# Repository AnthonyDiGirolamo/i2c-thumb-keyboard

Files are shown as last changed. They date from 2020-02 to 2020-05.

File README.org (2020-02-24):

* i2c-thumb-keyboard

  Handheld tactile switch keyboard using the [[http://www.ti.com/product/TCA8418][TCA8418]].

  For more info see these [[https://hackaday.io/project/162281-teensy-thumb-keyboard][hackaday.io]] posts:
  - [[https://hackaday.io/project/162281-teensy-thumb-keyboard/log/164899-working-on-v2][Working on v2]]
  - [[https://hackaday.io/project/162281-teensy-thumb-keyboard/log/165015-raspberry-pi-i2c-connection][Raspberry Pi i2c Connection]]

** v1.0 Photo
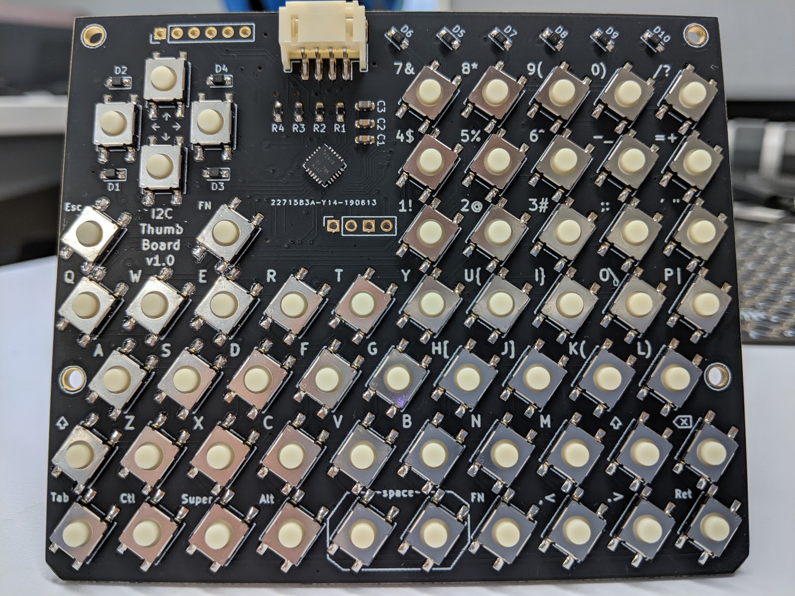
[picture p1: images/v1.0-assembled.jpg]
   

** BOM
   - 60x [[https://www.digikey.com/product-detail/en/panasonic-electronic-components/EVQ-Q2B03W/P12932SCT-ND/762922][EVQ-Q2B03W Tactile Switch]] (SW1-SW60)
   - 10x [[https://lcsc.com/product-detail/Switching-Diode_1N4148WS_C110221.html][1N4148WS Diode]] (D1-D10)
   - 1x [[https://lcsc.com/product-detail/Interface-ICs_TI_TCA8418RTWR_TCA8418RTWR_C138713.html][TCA8418]]
   - 2x [[https://lcsc.com/product-detail/Chip-Resistor-Surface-Mount_Uniroyal-Elec-0603WAF1002T5E_C25804.html][0603 10k Resistor]] (R1, R4)
   - 2x [[https://lcsc.com/product-detail/Chip-Resistor-Surface-Mount_Uniroyal-Elec-0603WAF4701T5E_C23162.html][0603 4.7k Resistor]] (R2, R3)
   - 2x [[https://lcsc.com/product-detail/Multilayer-Ceramic-Capacitors-MLCC-SMD-SMT_SAMSUNG_CL10B104KA8NNNC_100nF-104-10-25V_C1590.html][0603 0.1uF Capacitor]] (C1, C2)
   - 1x [[https://lcsc.com/product-detail/Multilayer-Ceramic-Capacitors-MLCC-SMD-SMT_SAMSUNG_CL10A106MQ8NNNC_10uF-106-20-6-3V_C1691.html][0603 10uF Capacitor]] (C3)
   - Optional:
     - 1x [[https://www.digikey.com/product-detail/en/jst-sales-america-inc/S4B-PH-SM4-TB(LF)(SN)/455-1751-1-ND/926848][JST PH Connector Socket S4B-PH-SM4-TB(LF)(SN)]]
     - 1x [[https://www.digikey.com/product-detail/en/jst-sales-america-inc/A04KR04KR26E152B/455-3151-ND/6194806][JST KR Jumper Cable]]

** Prior Work

   [[https://github.com/AnthonyDiGirolamo/teensy-thumb-keyboard][teensy-thumb-keyboard]]

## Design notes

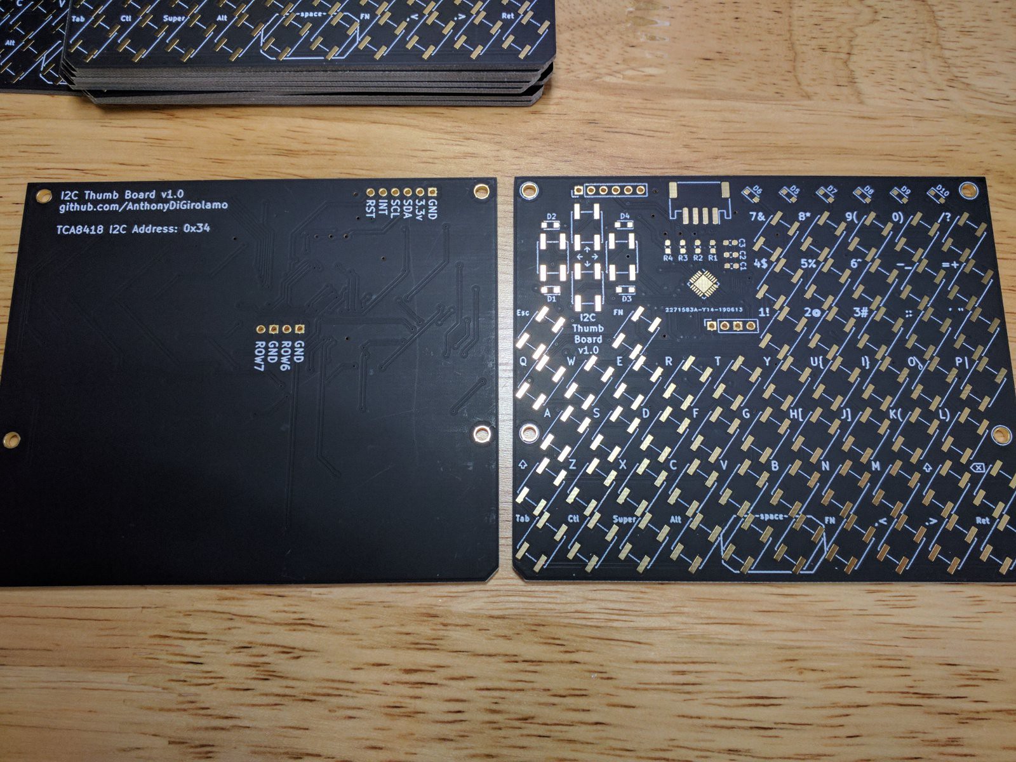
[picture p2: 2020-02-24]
images/v1.0-front-back.jpg

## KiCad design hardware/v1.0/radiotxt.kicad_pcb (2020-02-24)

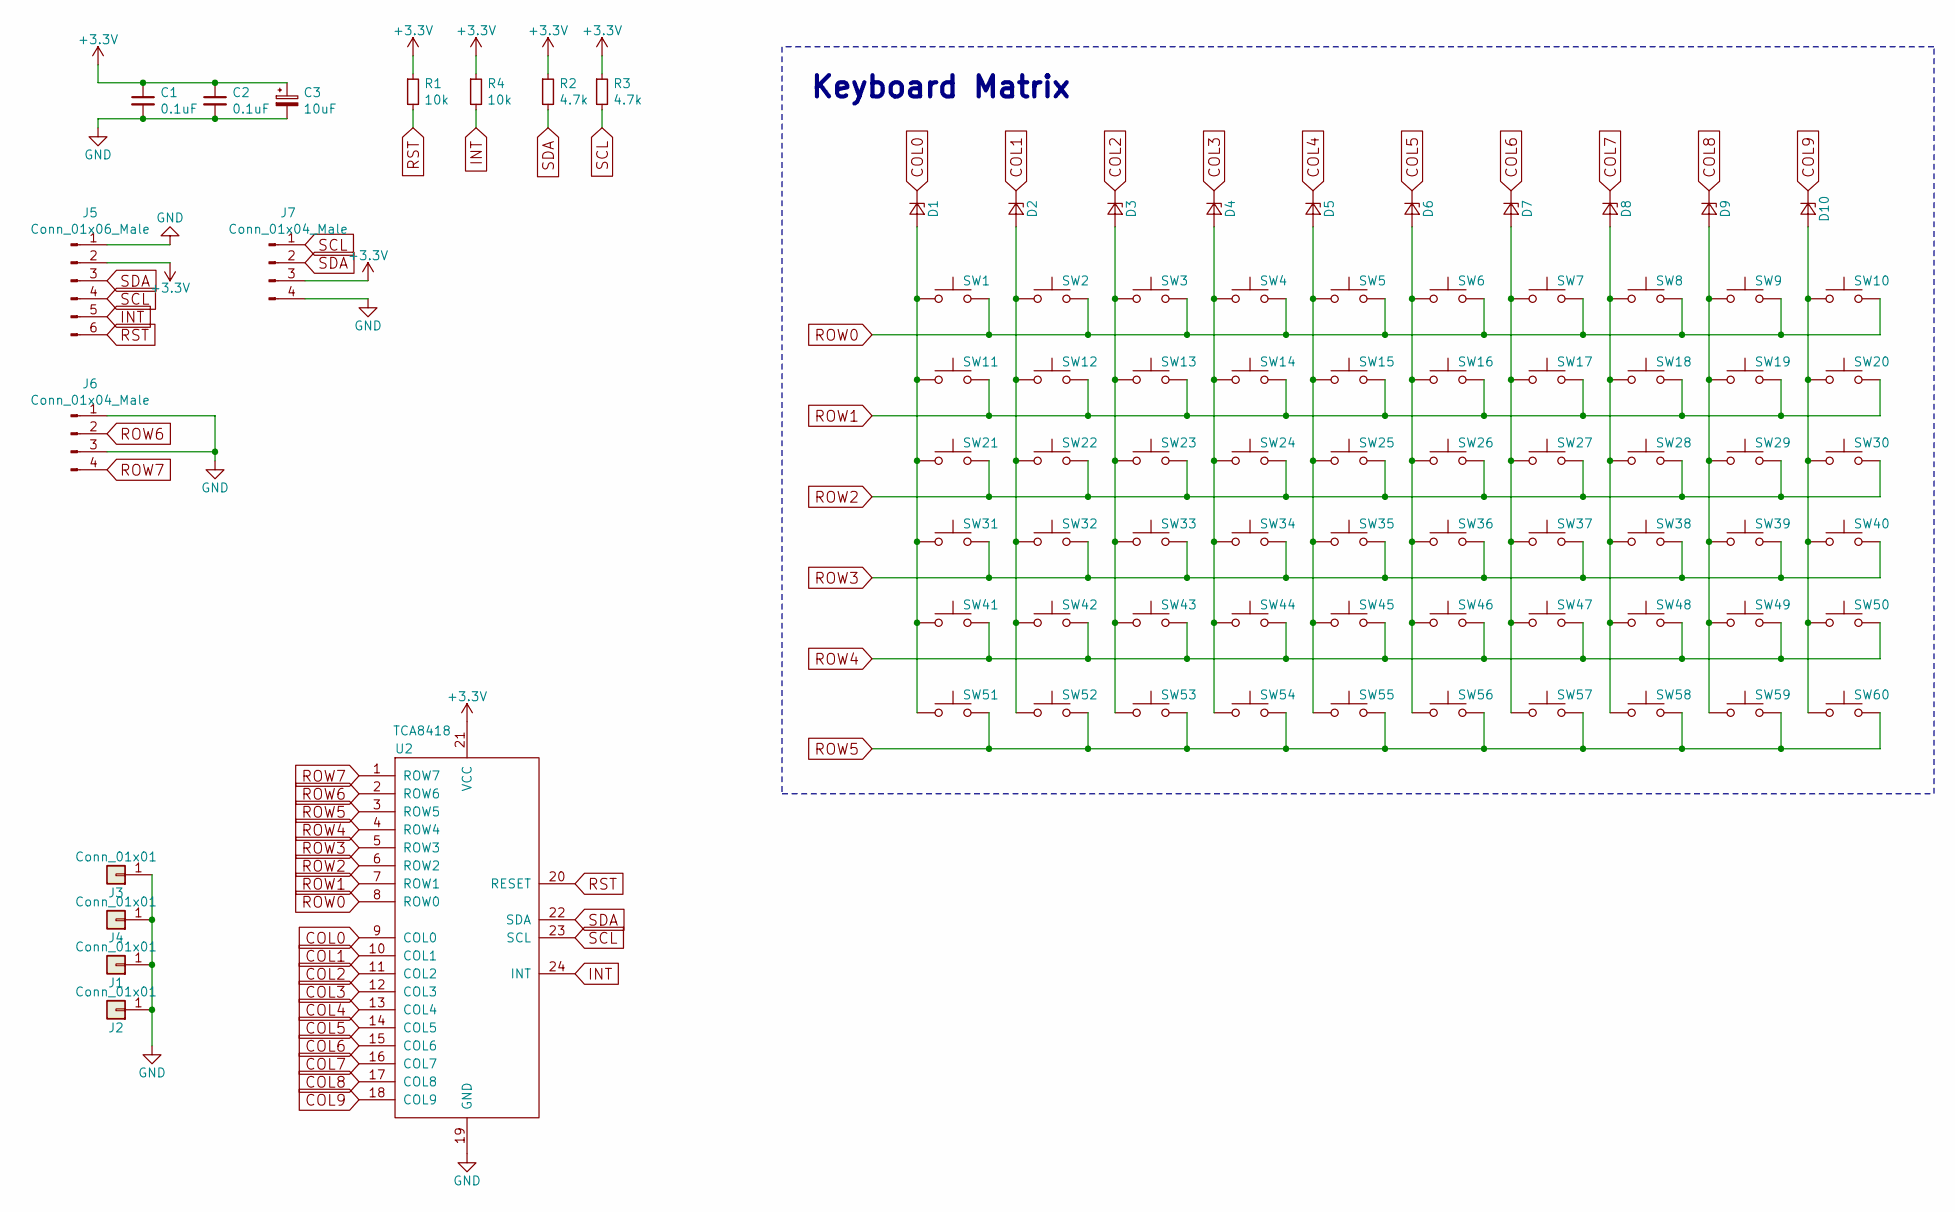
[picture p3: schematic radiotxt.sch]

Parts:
C1, C2: 0.1uF; C_0603_1608Metric_Pad1.05x0.95mm_HandSolder
C3: 10uF; C_0603_1608Metric_Pad1.05x0.95mm_HandSolder
D1, D2, D3, D4, D5, D6, D7, D8, D9, D10: D_Zener_Small; D_SOD-323_HandSoldering
J1, J2, J3, J4: Conn_01x01; 2.5MountingHole
J5: Conn_01x06_Male; PinHeader_1x06_P2.54mm_Vertical
J6: Conn_01x04_Male; PinSocket_1x04_P2.54mm_Vertical
J7: Conn_01x04_Male; JST_PH_S4B-PH-SM4-TB_1x04-1MP_P2.00mm_Horizontal
R1, R4: 10k; R_0603_1608Metric_Pad1.05x0.95mm_HandSolder
R2, R3: 4.7k; R_0603_1608Metric_Pad1.05x0.95mm_HandSolder
SW1, SW2, SW3, SW4, SW5, SW6, SW7, SW8, SW9, SW10, SW11, SW12, SW13, SW14, SW15, SW16, SW17, SW18, SW19, SW20, SW21, SW22, SW23, SW24, SW25, SW26, SW27, SW28, SW29, SW30, SW31, SW32, SW33, SW34, SW35, SW36, SW37, SW38, SW39, SW40, SW41, SW42, SW43, SW44, SW45, SW46, SW47, SW48, SW49, SW50, SW51, SW52, SW53, SW54, SW55, SW56, SW57, SW58, SW59, SW60: SW_Push; SW_SPST_EVQQ2
U2: TCA8418; WQFN-24-1EP_4x4mm_P0.5mm_EP2.7x2.7mm

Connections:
+3V3: C1.1, C2.1, C3.1, J5.2, J7.3, R1.1, R2.1, R3.1, R4.1, U2.21 (VCC)
COL0: D1.1 (K), U2.9 (COL0)
COL1: D2.1 (K), U2.10 (COL1)
COL2: D3.1 (K), U2.11 (COL2)
COL3: D4.1 (K), U2.12 (COL3)
COL4: D5.1 (K), U2.13 (COL4)
COL5: D6.1 (K), U2.14 (COL5)
COL6: D7.1 (K), U2.15 (COL6)
COL7: D8.1 (K), U2.16 (COL7)
COL8: D9.1 (K), U2.17 (COL8)
COL9: D10.1 (K), U2.18 (COL9)
GND: C1.2, C2.2, C3.2, J1.1, J2.1, J3.1, J4.1, J5.1, J6.1, J6.3, J7.4, U2.19 (GND)
INT: J5.5, R4.2, U2.24 (INT)
unnamed: D1.2 (A), SW1.1, SW11.1, SW21.1, SW31.1, SW41.1, SW51.1
unnamed: D2.2 (A), SW2.1, SW12.1, SW22.1, SW32.1, SW42.1, SW52.1
unnamed: D3.2 (A), SW3.1, SW13.1, SW23.1, SW33.1, SW43.1, SW53.1
unnamed: D4.2 (A), SW4.1, SW14.1, SW24.1, SW34.1, SW44.1, SW54.1
unnamed: D5.2 (A), SW5.1, SW15.1, SW25.1, SW35.1, SW45.1, SW55.1
unnamed: D6.2 (A), SW6.1, SW16.1, SW26.1, SW36.1, SW46.1, SW56.1
unnamed: D7.2 (A), SW7.1, SW17.1, SW27.1, SW37.1, SW47.1, SW57.1
unnamed: D8.2 (A), SW8.1, SW18.1, SW28.1, SW38.1, SW48.1, SW58.1
unnamed: D9.2 (A), SW9.1, SW19.1, SW29.1, SW39.1, SW49.1, SW59.1
unnamed: D10.2 (A), SW10.1, SW20.1, SW30.1, SW40.1, SW50.1, SW60.1
ROW0: SW1.2, SW2.2, SW3.2, SW4.2, SW5.2, SW6.2, SW7.2, SW8.2, SW9.2, SW10.2, U2.8 (ROW0)
ROW1: SW11.2, SW12.2, SW13.2, SW14.2, SW15.2, SW16.2, SW17.2, SW18.2, SW19.2, SW20.2, U2.7 (ROW1)
ROW2: SW21.2, SW22.2, SW23.2, SW24.2, SW25.2, SW26.2, SW27.2, SW28.2, SW29.2, SW30.2, U2.6 (ROW2)
ROW3: SW31.2, SW32.2, SW33.2, SW34.2, SW35.2, SW36.2, SW37.2, SW38.2, SW39.2, SW40.2, U2.5 (ROW3)
ROW4: SW41.2, SW42.2, SW43.2, SW44.2, SW45.2, SW46.2, SW47.2, SW48.2, SW49.2, SW50.2, U2.4 (ROW4)
ROW5: SW51.2, SW52.2, SW53.2, SW54.2, SW55.2, SW56.2, SW57.2, SW58.2, SW59.2, SW60.2, U2.3 (ROW5)
ROW6: J6.2, U2.2 (ROW6)
ROW7: J6.4, U2.1 (ROW7)
RST: J5.6, R1.2, U2.20 (RESET)
SCL: J5.4, J7.1, R3.2, U2.23 (SCL)
SDA: J5.3, J7.2, R2.2, U2.22 (SDA)

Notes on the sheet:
Keyboard Matrix

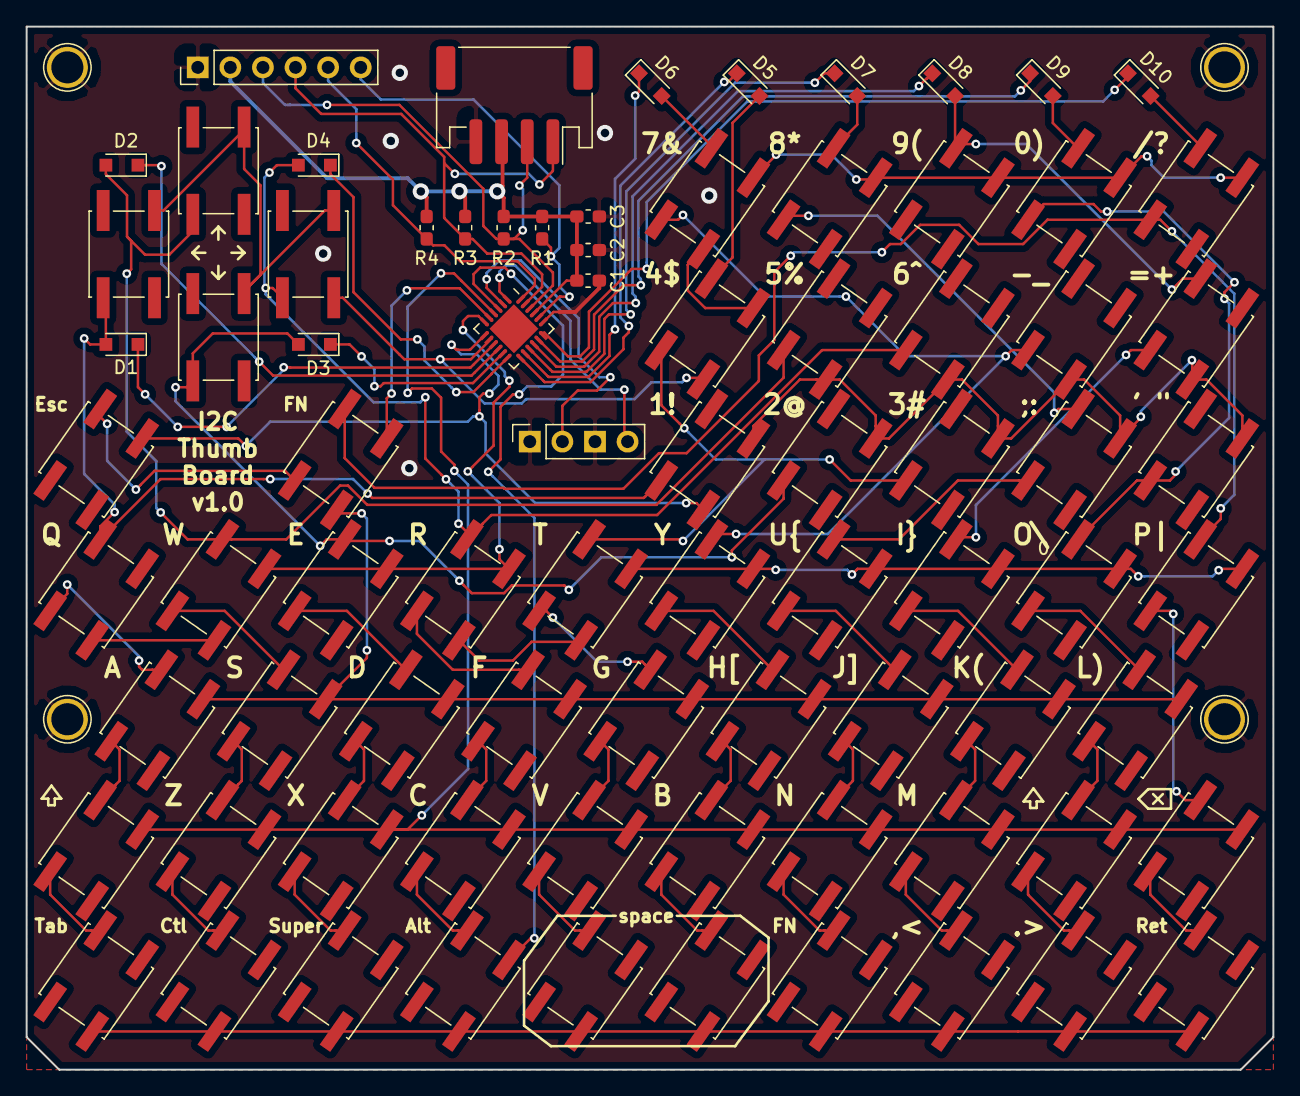
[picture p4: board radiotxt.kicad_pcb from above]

Board: 2 copper layers, 97.2 x 81.3 mm, 85 parts (0 on the bottom side), 34 nets.

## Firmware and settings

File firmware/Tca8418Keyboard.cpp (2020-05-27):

#include "Tca8418Keyboard.h"

Tca8418Keyboard::Tca8418Keyboard(uint8_t numrows, uint8_t numcols) {
  tca8418_address = TCA8418_I2C_ADDRESS;
  num_rows = numrows;
  num_cols = numcols;

  delta_micros = 0;
  last_update_micros = 0;
  this_update_micros = 0;

  pressed_list = new PressedKey[KEY_EVENT_LIST_SIZE];
  released_list = new ReleasedKey[KEY_EVENT_LIST_SIZE];
  matrix_state = new uint16_t[num_rows];
  matrix_state_prev = new uint16_t[num_rows];

}

Tca8418Keyboard::~Tca8418Keyboard(void) {
  delete [] matrix_state_prev;
  delete [] matrix_state;
  delete [] pressed_list;
  delete [] released_list;
}

void Tca8418Keyboard::begin(void) {
  Wire.begin();

  /*
    | ADDRESS | REGISTER NAME | REGISTER DESCRIPTION | BIT7 | BIT6 | BIT5 | BIT4 | BIT3 | BIT2 | BIT1 | BIT0 |
    |---------+---------------+----------------------+------+------+------+------+------+------+------+------|
    |    0x1D | KP_GPIO1      | Keypad/GPIO Select 1 | ROW7 | ROW6 | ROW5 | ROW4 | ROW3 | ROW2 | ROW1 | ROW0 |
    |    0x1E | KP_GPIO2      | Keypad/GPIO Select 2 | COL7 | COL6 | COL5 | COL4 | COL3 | COL2 | COL1 | COL0 |
    |    0x1F | KP_GPIO3      | Keypad/GPIO Select 3 | N/A  | N/A  | N/A  | N/A  | N/A  | N/A  | COL9 | COL8 |
  */

  // everything enabled in key scan mode
  uint8_t enabled_rows = 0x3F;
  uint16_t enabled_cols = 0x3FF;

  write(REGISTER_KP_GPIO1, enabled_rows);
  write(REGISTER_KP_GPIO2, (uint8_t)(0xFF & enabled_cols));
  write(REGISTER_KP_GPIO3, (uint8_t)(0x03 & (enabled_cols >> 8)));

  /*
    BIT: NAME

    7: AI
    Auto-increment for read and write operations; See below table for more information
    0 = disabled
    1 = enabled

    6: GPI_E_CFG
    GPI event mode configuration
    0 = GPI events are tracked when keypad is locked
    1 = GPI events are not tracked when keypad is locked

    5: OVR_FLOW_M
    Overflow mode
    0 = disabled; Overflow data is lost
    1 = enabled; Overflow data shifts with last event pushing first event out

    4: INT_CFG
    Interrupt configuration
    0 = processor interrupt remains asserted (or low) if host tries to clear interrupt while there is
    still a pending key press, key release or GPI interrupt
    1 = processor interrupt is deasserted for 50 μs and reassert with pending interrupts

    3: OVR_FLOW_IEN
    Overflow interrupt enable
    0 = disabled; INT is not asserted if the FIFO overflows
    1 = enabled; INT becomes asserted if the FIFO overflows

    2: K_LCK_IEN
    Keypad lock interrupt enable
    0 = disabled; INT is not asserted after a correct unlock key sequence
    1 = enabled; INT becomes asserted after a correct unlock key sequence

    1: GPI_IEN
    GPI interrupt enable to host processor
    0 = disabled; INT is not asserted for a change on a GPI
    1 = enabled; INT becomes asserted for a change on a GPI

    0: KE_IEN
    Key events interrupt enable to host processor
    0 = disabled; INT is not asserted when a key event occurs
    1 = enabled; INT becomes asserted when a key event occurs
   */

  // 10111001 xB9 -- fifo overflow enabled
  // 10011001 x99 -- fifo overflow disabled
  write(REGISTER_CFG, 0x99);

  clear_released_list();
  clear_pressed_list();

  delayMicroseconds(100);
}

void Tca8418Keyboard::write(uint8_t register_address, uint8_t data) {
  Wire.beginTransmission(tca8418_address);
  Wire.write((uint8_t) register_address);
  Wire.write((uint8_t) data);
  Wire.endTransmission();
}

bool Tca8418Keyboard::read(uint8_t register_address, uint8_t *data) {
  Wire.beginTransmission(tca8418_address);
  Wire.write(register_address);
  Wire.endTransmission();

  uint8_t timeout=0;
  Wire.requestFrom(tca8418_address, (uint8_t) 0x01);

  while(Wire.available() < 1) {
    timeout++;
    if(timeout > 100) {
      return false;
    }
    delayMicroseconds(1);
  }
  *data = Wire.read();
  return true;
}

bool Tca8418Keyboard::update() {
  last_update_micros = this_update_micros;
  uint8_t key_code, key_down, key_event, key_row, key_col;

  key_event = get_key_event();
  // TODO: read gpio R7/R6 status? 0x14 bits 7&6
  // read(0x14, &new_keycode)

  this_update_micros = micros();
  delta_micros = this_update_micros - last_update_micros;

  // if there is a new event
  if (key_event > 0) {
    key_code = key_event & 0x7F;
    key_down = (key_event & 0x80) >> 7;
    key_row = key_code / num_cols;
    key_col = key_code % num_cols;

    Serial.println(key_code);
    Serial.println(key_down);

    // always clear the released list
    clear_released_list();

    if (key_down) {
      add_pressed_key(key_row, key_col);
      // TODO reject ghosts (assume multiple key presses with the same hold time are ghosts.)

    }
    else {
      add_released_key(key_row, key_col);
      remove_pressed_key(key_row, key_col);
    }

    return true;
  }

  // increment hold times for pressed keys
  for (int i=0; i<pressed_key_count; i++) {
    pressed_list[i].hold_time += delta_micros;
  }

  return false;
}
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

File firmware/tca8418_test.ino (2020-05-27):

#include <Wire.h>
#include "Tca8418Keyboard.h"

Tca8418Keyboard key_matrix(6, 10);

// uint32_t startmicros, endmicros;
void setup() {
  Serial.begin(115200);
  delay(2000);
  Serial.println("key_matrix.begin");
  key_matrix.begin();
  Serial.println("key_matrix.begin done");
}

void loop() {

  // uint8_t key;
  // key = key_matrix.get_key_event();
  // if (key > 0) {
  //   Serial.print((key&0x7F), HEX); //print keycode masking the key down/key up bit (bit7)
  //   if(key & 0x80) {
  //     Serial.println(" key down");
  //   } else {
  //     Serial.println(" key up");
  //   }
  // }

  if (key_matrix.update()) {
    Serial.print("pressed [");
    Serial.print(key_matrix.pressed_key_count);
    Serial.print("]: ");
    for (int i=0; i<key_matrix.pressed_key_count; i++) {
      Serial.print(key_matrix.pressed_list[i].row);
      Serial.print(",");
      Serial.print(key_matrix.pressed_list[i].col);
      Serial.print(",");
      Serial.print(key_matrix.pressed_list[i].hold_time);
      Serial.print("  ");
    }
    Serial.println();

    Serial.print("released [");
    Serial.print(key_matrix.released_key_count);
    Serial.print("]: ");
    for (int i=0; i<key_matrix.released_key_count; i++) {
      Serial.print(key_matrix.released_list[i].row);
      Serial.print(",");
      Serial.print(key_matrix.released_list[i].col);
      Serial.print("  ");
    }
    Serial.println();
  }

}

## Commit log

2020-02-24 Add v1.0 kicad files
    [radiotxt-2018-07-13-08-14-04.sch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]
2020-05-27 add example arduino firmware code
